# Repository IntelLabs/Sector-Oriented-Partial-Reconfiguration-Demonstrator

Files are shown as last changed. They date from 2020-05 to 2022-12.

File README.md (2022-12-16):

# Sector-Oriented-Partial-Reconfiguration-Demonstrator

> :warning: **DISCONTINUATION OF PROJECT** - 
> *This project will no longer be maintained by Intel.
> Intel has ceased development and contributions including, but not limited to, maintenance, bug fixes, new releases, or updates, to this project.*
> **Intel no longer accepts patches to this project.**
> *If you have an ongoing need to use this project, are interested in independently developing it, or would like to maintain patches for the open source software community, please create your own fork of this project.*

Software Requirement: Intel® Quartus® Prime Design Suite 18.0.0/219

Target Device: Stratix 10 H-tile ES1 1SG280HU2F50E2VGS1

This is a 9-sector 3x3 NoC design, where data master of a sector can send packets to any other 8 sectors by forwarding to neighbour sectors. In this version, each sector has customized number of north, east, south, west and local ports, where address widths of the ports vary for each sector. No manual control of address span extender involved.

Origin data master (Nios II Processor) can communicated to any sector by writing to the address of the slave (FIFO). The longer the data path, the more sectors the packet will be rerouted to, as each sector can only communicate with its immediate north/east/south/west neighbour.

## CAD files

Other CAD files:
test_noc/project/stp2.stp

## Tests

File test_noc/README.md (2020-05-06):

# Design Compilation
1. Open Quartus project file test_noc.qpf and change to test_noc revision (base revision) if it's not already loaded.
2. Open system.qsys in Platform Designer and generate HDL.
3. Perform full design compilation in Quartus. This might take ~1 hour.
4. Export Design Partition of base revision for other project revisions:- 
	* Export final snapshot of root_partition as test_noc_static.qdb
	* Export final snapshot of s1_parent_partition as s1_parent_partition_default_final.qdb     
	* Export final snapshot of s2_parent_partition as s2_parent_partition_default_final.qdb 
	* Export final snapshot of s3_parent_partition as s3_parent_partition_default_final.qdb 
	* Export final snapshot of s4_parent_partition as s4_parent_partition_default_final.qdb 
	* Export final snapshot of s5_parent_partition as s5_parent_partition_default_final.qdb 
	* Export final snapshot of s6_parent_partition as s6_parent_partition_default_final.qdb 
	* Export final snapshot of s7_parent_partition as s7_parent_partition_default_final.qdb 
	* Export final snapshot of s8_parent_partition as s8_parent_partition_default_final.qdb 
* This step must be repeated everytime the base revision is recompiled. 
5. Switch to test_noc_v1 revision. Perform full design compilation. 
6. Repeat for test_noc_v2 and test_noc_bad revisions.

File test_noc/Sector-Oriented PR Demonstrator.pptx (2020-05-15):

## Sector-oriented pr demonstrator

Intel Labs

## Legal Disclaimers

- Intel provides these materials as-is, with no express or implied warranties.
- All products, dates, and figures specified are preliminary, based on current expectations, and are subject to change without notice.
- Intel processors, chipsets, and desktop boards may contain design defects or errors known as errata, which may cause the product to deviate from published specifications. Current characterized errata are available on request.
- Intel technologies' features and benefits depend on system configuration and may require enabled hardware, software or service activation. Performance varies depending on system configuration. No product or component can be absolutely secure. Check with your system manufacturer or retailer or learn more at http://intel.com.
- Some results have been estimated or simulated using internal Intel analysis or architecture simulation or modeling, and provided to you for informational purposes. Any differences in your system hardware, software or configuration may affect your actual performance.
- Intel, Quartus, Stratix, the Intel logo and the Stratix logo are trademarks of Intel Corporation in the United States and other countries. Other names and brands may be claimed as the property of others. *Other names and brands may be claimed as the property of others.
© Intel Corporation 2020

## Sector NoC Infrastructure

- North, East, South, West In/Out ports for data transfer (AVMM)
- Data packet will be stored in FIFO of destination sector
- Security filter can be enabled/disabled during runtime to block/unblock data transfer to any sector
- PR region controllers for each NESW Ports and controlled via out-of-bound signals (conduit) from the Master

## 3x3 NoC

- Sector 0-8
  - Sector 0 as the Master with debug interface
- Logic-lock placement
  - Parent partition is sector-aligned
    - Entire sector (NoC + user logic)
  - Child partition at the centre of a sector
    - User logic only
- Performance
  - Frequency 100MHz; Fmax 133MHz
  - Sector-sector bandwidth 133MHz / 12 cycles latency * 4 bytes/transfer = 44MB/s (non-burst)
- Resource Utilization
  - NoC infrastructure resource varies from sector to sector
  - Ranges from 1000 - 2000 ALMs per sector

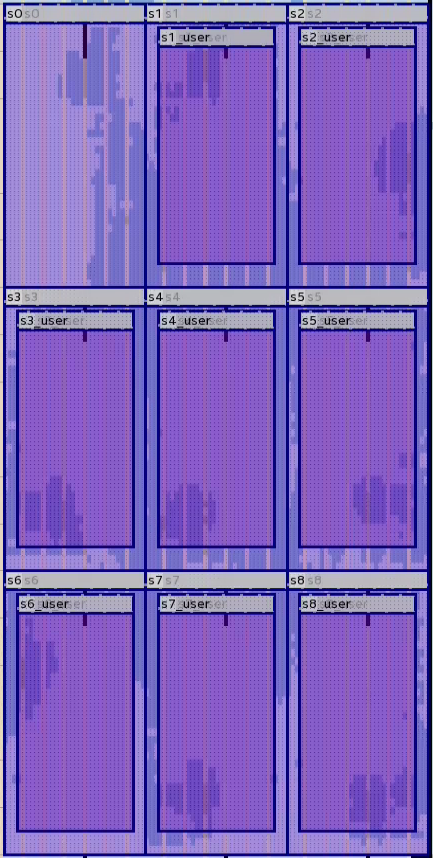
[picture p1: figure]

## Partial Reconfiguration 101

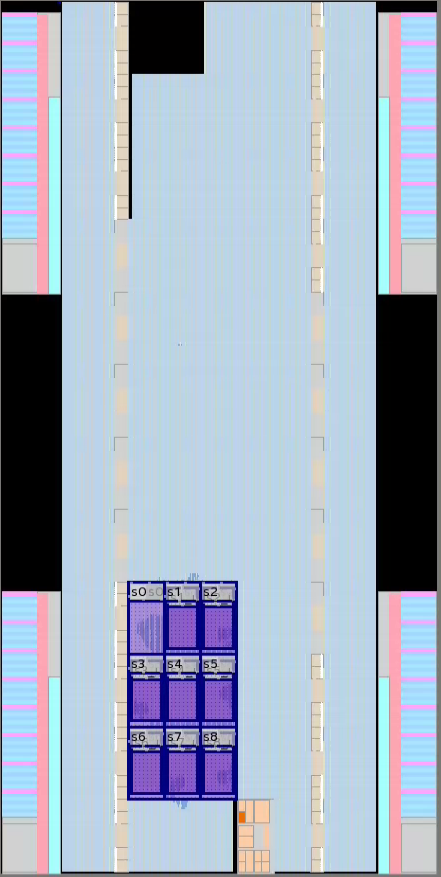
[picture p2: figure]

- Ability to reconfigure part of the design (PR region); while the rest of the design is running (static region)
- Default .sof will configure the entire chip, both static and PR regions (orange boxes)
- Child partition can be recompiled with different user logic persona while NoC infrastructure in parent partition for each sector remains the same
- Parent.rbf (sector-aligned) will be configured to achieve sector PR
- Adjacent interfaces of PR region must be frozen prior to PR to avoid unknown data/command being asserted

Static Region

B

C

A

PR regions

## PR Mechanism

- Example: Sector 4 Reconfiguration
- Master asserts freeze requests to PR region controllers of neighbouring ports (in red)
- Master asserts reset to sector 4
- Program sector 4 parent_partition.rbf
- Master asserts unfreeze requests to PR region controllers
- Master de-asserts reset

## Demo

- Each user logic consists of Nios II Processor, memory, unique system ID
- The processor will poll the status of local FIFO periodically and upon detecting data it will return the data + ID to master (sector 0)
- All commands will be sent from the master via System Console
- Dev kit: Stratix 10 GX FPGA Development Kit H-tile (ES)
- Images are compiled using Quartus v18.0

ID

Data

## Board bring-up

- Program test_noc.sof using Programmer
- In System Console, source demo script
  - System reset via jtag_debug_reset_system
  - open_service master for sector0 master

## Command list

- sXwr <data>
  - Sector0 master writes <data> to sector
  - E.g. s1wr 0x1111
- sXfreeze
  - Sector0 master freezes sectorX PR region controllers and reset sectorX
  - E.g. s1freeze
- sXunfreeze
  - Sector0 master unfreezes sectorX PR region controllers and de-asserts reset to sector
  - E.g. s1unfreeze
- sXfilter <data>
  - Enable security filter of sector
  - E.g. s1filter 0x1

regwr <addr> <data>
Sector0 master writes <data> to <addr>
E.g. regwr 0x100 0x5678
regrd <addr>
Sector0 master reads from <addr>
E.g. regrd 0x40000
sector_write <data>
Sector0 master writes <data> to all 8 sectors
E.g. sector_write 0x5376
fiford <num>
Sector0 master reads from local FIFO for <num(decimal)> of times
E.g. fiford 8

## Sanity Check

- Master writes to 8 sectors
- Each sector should return the data + ID to master

FIFO Count increases with each write

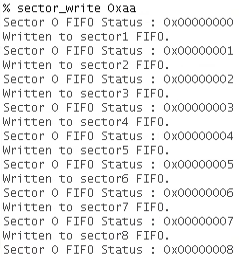
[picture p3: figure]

Read 8 Master’s FIFO data

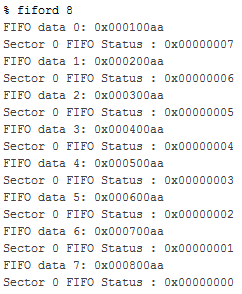
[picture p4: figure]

<- From sector1
<- From sector2
<- From sector3
<- From sector4
<- From sector5
<- From sector6
<- From sector7
<- From sector8

## Sector Partial Reconfiguration

- Master asserts freeze requests to PR region controllers and reset to PR sector
- Close master service in System Console and program test_noc_v2.s1_parent_partition.rbf in Programmer
- Reopen master service and send unfreeze request
- Repeat sanity check

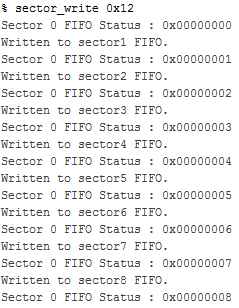
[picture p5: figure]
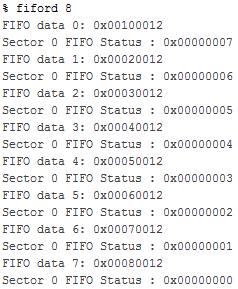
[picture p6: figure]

ID changed from 1 to 10

## Security Filter

- PR a sector with ‘bad’ rbf which repetitively writes 0xFFFFFFFF to sector 0 every few seconds
- Enable security filter of data from that sector to sector0
- Sector 0 will no longer receive data from that sector

FIFO count increasing without any write

Read sector0 FIFO count

Bit | Field | Default value | Descriptions
0 | Sector 0 access | 0 | Write 1 to this bit to block access to sector0. Write 0 to this bit to allow access to sector0.
1 | Sector 1 access | 0 | Write 1 to this bit to block access to sector1. Write 0 to this bit to allow access to sector1.
2 | Sector 2 access | 0 | Write 1 to this bit to block access to sector2. Write 0 to this bit to allow access to sector2.
3 | Sector 3 access | 0 | Write 1 to this bit to block access to sector3. Write 0 to this bit to allow access to sector3.
4 | Sector 4 access | 0 | Write 1 to this bit to block access to sector4. Write 0 to this bit to allow access to sector4.
5 | Sector 5 access | 0 | Write 1 to this bit to block access to sector5. Write 0 to this bit to allow access to sector5.
6 | Sector 6 access | 0 | Write 1 to this bit to block access to sector6. Write 0 to this bit to allow access to sector6.
7 | Sector 7 access | 0 | Write 1 to this bit to block access to sector7. Write 0 to this bit to allow access to sector7.
8 | Sector 8 access | 0 | Write 1 to this bit to block access to sector8. Write 0 to this bit to allow access to sector8.

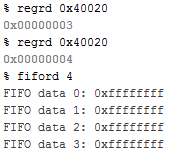
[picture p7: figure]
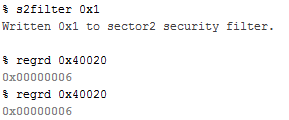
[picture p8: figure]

FIFO count no longer increasing

Enable filter to block data transfer from sector2 to sector0

Security Filter Control Register

## NoC Limitations

- NoC infrastructure of each sector is static as the sector AVMM addresses are hard-coded
- Current design doesn’t support burst data transfer
- Sectors are not able to trace the origin of incoming data
- Frozen state during PR will impact data transfer of other sector

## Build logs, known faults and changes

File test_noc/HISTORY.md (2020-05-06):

# Revision History

* February 15, 2019
	* first version of demo-ready design
	* Consists of 4 revisions: base, v1 - swap sys id among sectors, v2 - all sys id = 10, bad - emulate bad tenant
